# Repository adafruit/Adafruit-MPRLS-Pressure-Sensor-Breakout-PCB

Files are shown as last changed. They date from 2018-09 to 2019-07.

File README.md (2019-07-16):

## Adafruit MPRLS Ported Pressure Sensor Breakout - 0 to 25 PSI PCB

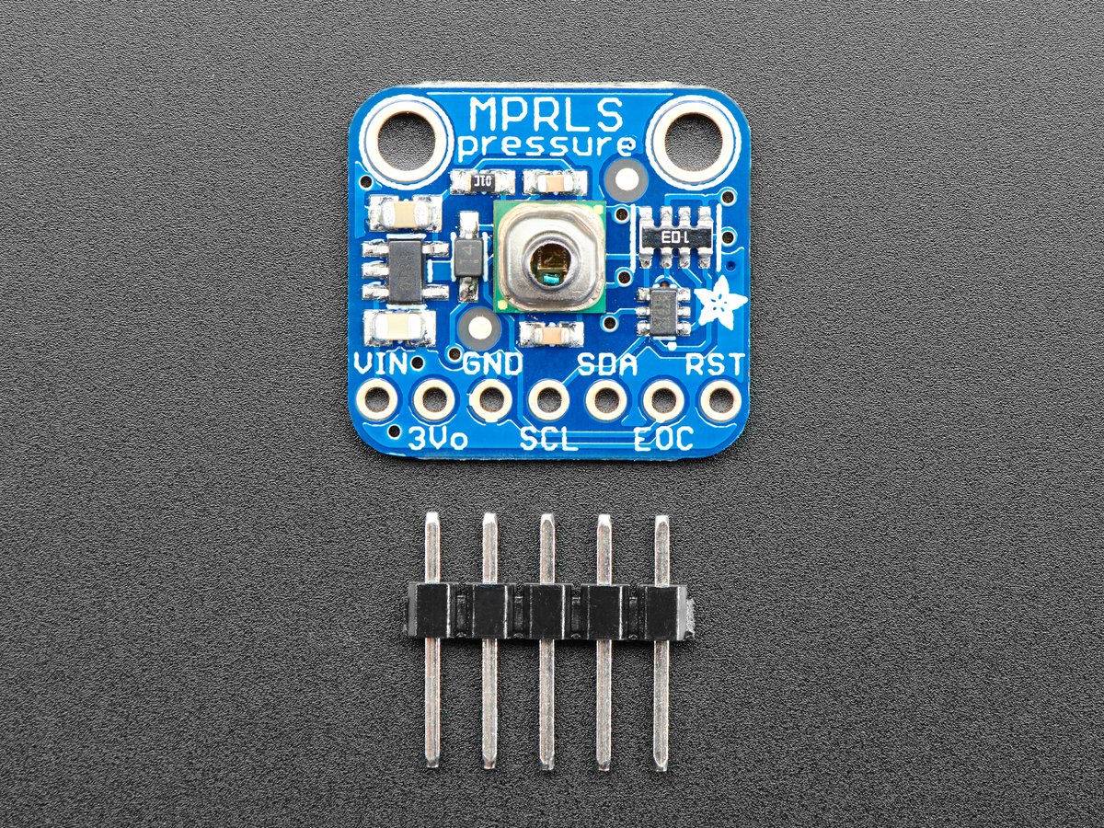
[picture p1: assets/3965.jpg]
<a href="http://www.adafruit.com/products/3965"><br/>
Click here to purchase one from the Adafruit shop</a>

PCB files for the Adafruit MPRLS Ported Pressure Sensor Breakout - 0 to 25 PSI. Format is EagleCAD schematic and board layout
* https://www.adafruit.com/product/3965

### Description

We stock a few barometric pressure sensors, great for altitude and weather measurements. This pressure sensor is special because it comes with a metal port! Unlike other pressure sensors, you can easily attach a tube to it, to measure air pressure inside a close space. In particular we think this would be a great sensor for use with making DIY assistive tech "Sip & Puff" interfaces, or measuring the pressure within a vacuum chamber or other pressurized container.

Unlike most ported pressure sensors, this one uses I2C, it's really easy to use with any microcontroller. Inside is a silicone-gel covered pressure sensing gauge with a pre-calibrated and compensated 24 bit ADC. We have [example code and libraries for Arduino](https://github.com/adafruit/Adafruit_MPRLS) or [CircuitPython/Python](https://github.com/adafruit/Adafruit_CircuitPython_MPRLS). You can measure absolute pressure 0 to 25 PSI, which is a great range since ambient pressure here on Earth is about 14.5 PSI.

The port is made of stainless steel and is 3.7mm long and 2.5mm diameter. It doesn't come with tubing so be sure to purchase some tubing to attach to the port.

We've placed this nice sensor on a breakout board with 3.3V power regulation and level shifting so you can use it with any kind of microcontroller or microcomputer, from an Arduino compatible to Raspberry Pi

### License

Adafruit invests time and resources providing this open source design, please support Adafruit and open-source hardware by purchasing products from [Adafruit](https://www.adafruit.com)!

Designed by Limor Fried/Ladyada for Adafruit Industries.

Creative Commons Attribution/Share-Alike, all text above must be included in any redistribution. See license.txt for additional details.

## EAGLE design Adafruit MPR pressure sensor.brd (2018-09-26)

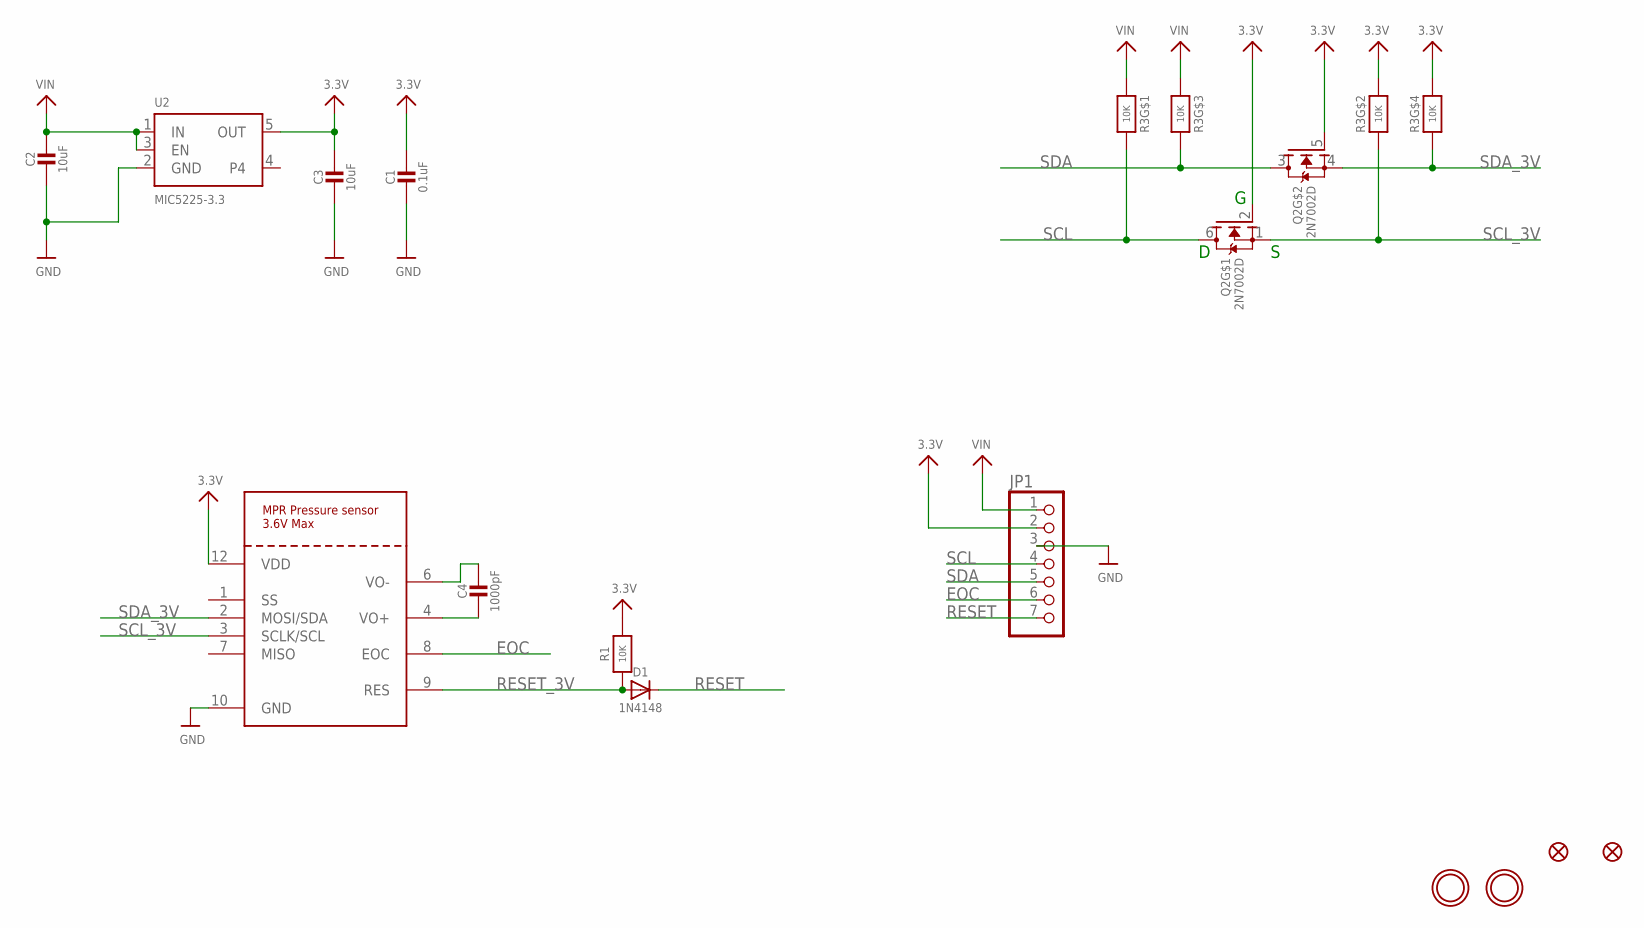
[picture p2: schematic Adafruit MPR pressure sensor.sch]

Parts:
C1: 0.1uF; 0603-NO
C2, C3: 10uF; 0805-NO
C4: 1000pF; 0603-NO
D1: 1N4148; SOD-323
FID1, FID2: FIDUCIAL_1MM
JP1: HEADER-1X770MIL; 1X07_ROUND_70
Q2: 2N7002D; SOT363
R1: 10K; 0603-NO
R3: 10K; RESPACK_4X0603
U2: MIC5225-3.3; SOT23-5
U$3, U$4: MOUNTINGHOLE2.5; MOUNTINGHOLE_2.5_PLATED
U$18: MPR_SERIES_I2C_PRESSURE

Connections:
3.3V: C1.1, C3.1, JP1.2, Q2.2 (G), Q2.5 (G), R1.2, R3.2 (1), R3.4 (1), U2.5 (OUT), U$18.12 (VDD)
EOC: JP1.6, U$18.8 (EOC)
GND: C1.2, C2.2, C3.2, JP1.3, U2.2 (GND), U$18.10 (GND)
unnamed: C4.2, U$18.4 (VO+)
unnamed: C4.1, U$18.6 (VO-)
RESET: D1.C, JP1.7
RESET_3V: D1.A, R1.1, U$18.9 (RES)
SCL: JP1.4, Q2.6 (D), R3.8 (2)
SCL_3V: Q2.1 (S), R3.7 (2), U$18.3 (SCLK/SCL)
SDA: JP1.5, Q2.3 (D), R3.6 (2)
SDA_3V: Q2.4 (S), R3.5 (2), U$18.2 (MOSI/SDA)
VIN: C2.1, JP1.1, R3.1, R3.3 (1), U2.1 (IN), U2.3 (EN)

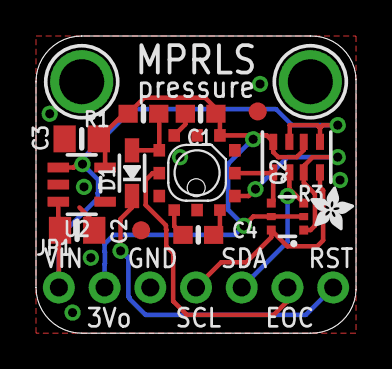
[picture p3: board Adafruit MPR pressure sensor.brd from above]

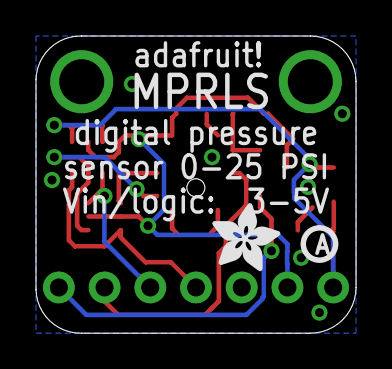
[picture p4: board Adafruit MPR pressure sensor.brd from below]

Board: 2 copper layers, 17.8 x 16.5 mm, 18 parts (2 on the bottom side), 12 nets.

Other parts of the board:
U$1: ADAFRUIT_3.5MM
U$8: ADAFRUIT_2.5MM
U$27: PCBFEAT-REV-040

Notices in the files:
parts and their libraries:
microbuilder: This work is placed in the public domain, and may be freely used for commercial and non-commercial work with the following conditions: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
